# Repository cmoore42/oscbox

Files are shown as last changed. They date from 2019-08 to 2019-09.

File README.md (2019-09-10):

# oscbox
Encoders for the ETC EOS family of lighting consoles using OSC and an Orange Pi Zero

## Overview
The purpose of this project is to create encoder wheels for the ETC EOS family of lighting software.
Specifically, the target is a PC or Mac running the EOS software.
It's possible this would work with a physical lighting console but it hasn't been tested.

The project was inspired by ETC's "lighthack" project.  
Their "box_1" implements two encoder wheels, one for PAN and one for TILT.
I wanted the same, but I wanted four wheels to match the wheels on an Ion console, 
and I wanted the wheels to be multi-function like the console wheels are.

## Details
For detailed descriptions of the code, the hardware, and the enclosure, [see the Wiki](https://github.com/cmoore42/oscbox/wiki)

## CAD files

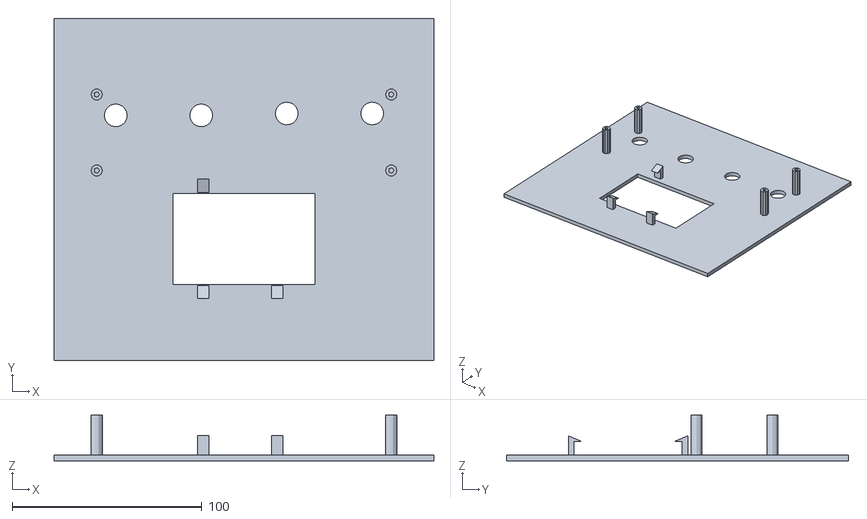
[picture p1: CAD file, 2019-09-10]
enclosure/panel.stl
200.0 x 180.0 x 24.0

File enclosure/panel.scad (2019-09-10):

encoder_zero_x = 100-(45/2)-45-20;
encoder_zero_y = 130-35;
encoder_hole_size = 6;

difference() {
    cube([200, 180, 3]);
    translate([100-(75/2), 40, -5])
        cube([75, 48, 20]);
    translate([100-(45/2)-45, 129, -2])
        cylinder(h=7, r1=encoder_hole_size, r2=encoder_hole_size);
    translate([100-(45/2), 129, -2])
        cylinder(h=7, r1=encoder_hole_size, r2=encoder_hole_size);
    translate([100+(45/2), 130, -2])
        cylinder(h=7, r1=encoder_hole_size, r2=encoder_hole_size);
    translate([100+(45/2)+45, 130, -2])
        cylinder(h=7, r1=encoder_hole_size, r2=encoder_hole_size);   
}

translate([75.5, 32.5, 3]) hook();
translate([114.5, 32.5, 3]) hook();
translate([81.5, 95.5, 3]) rotate([0, 0, 180]) hook();

translate([encoder_zero_x+10, encoder_zero_y+45, 0])
        standoff();
translate([encoder_zero_x+10, encoder_zero_y+5, 0])
        standoff();
translate([encoder_zero_x+165, encoder_zero_y+45, 0])
        standoff();
translate([encoder_zero_x+165, encoder_zero_y+5, 0])
        standoff();

module hook() {
    cube([6, 3, 7.2]);
    translate([6, 7, 7.2])
    rotate([90, 0, 0])
    rotate([0, 270, 0])
    linear_extrude(height=6) {
        polygon([[0,0], [7,0], [7,3], [0, 0]]);
    }      
}

module standoff() {
    difference() {
        cylinder(h=24, r1=3, r2=3);
        translate([0, 0, 15])
            cylinder(h=10, r1=1.5, r2=1.5);
    }
}

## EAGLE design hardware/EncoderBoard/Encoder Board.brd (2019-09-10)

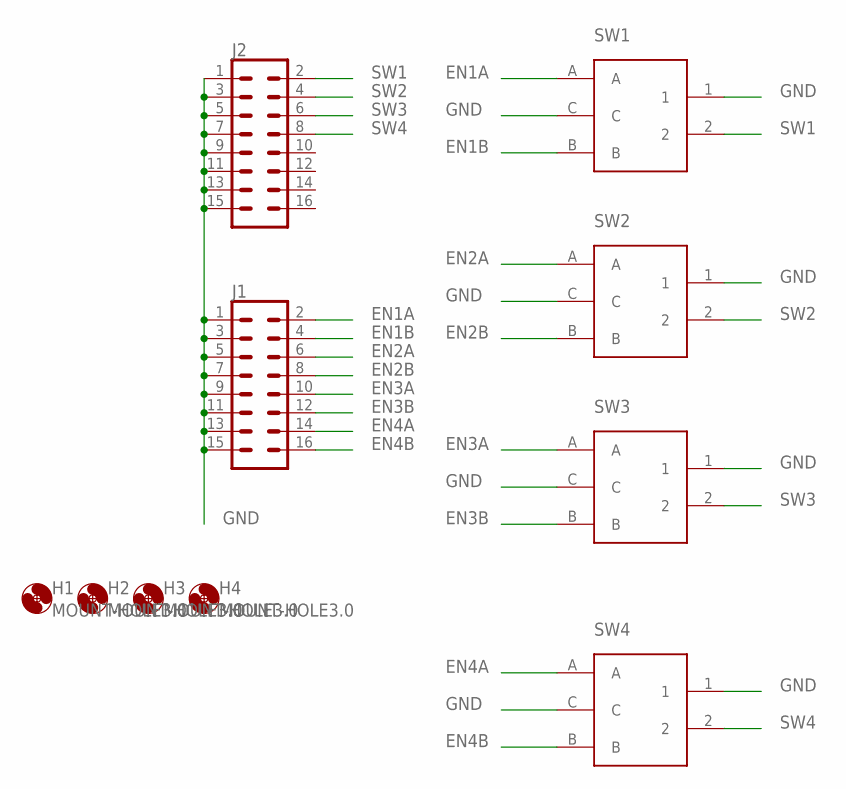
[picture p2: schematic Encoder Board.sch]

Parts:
H1, H2, H3, H4: MOUNT-HOLE3.0; 3,0
J1, J2: CONN_08X2; 2X8
SW1, SW2, SW3, SW4: PEC11R-4220F-S0012-ND; PEC11R-4XXXF-SXXXX

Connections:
EN1A: J1.2, SW1.A
EN1B: J1.4, SW1.B
EN2A: J1.6, SW2.A
EN2B: J1.8, SW2.B
EN3A: J1.10, SW3.A
EN3B: J1.12, SW3.B
EN4A: J1.14, SW4.A
EN4B: J1.16, SW4.B
GND: J1.1, J1.3, J1.5, J1.7, J1.9, J1.11, J1.13, J1.15, J2.1, J2.3, J2.5, J2.7, J2.9, J2.11, J2.13, J2.15, SW1.1, SW1.C, SW2.1, SW2.C, SW3.1, SW3.C, SW4.1, SW4.C
SW1: J2.2, SW1.2
SW2: J2.4, SW2.2
SW3: J2.6, SW3.2
SW4: J2.8, SW4.2

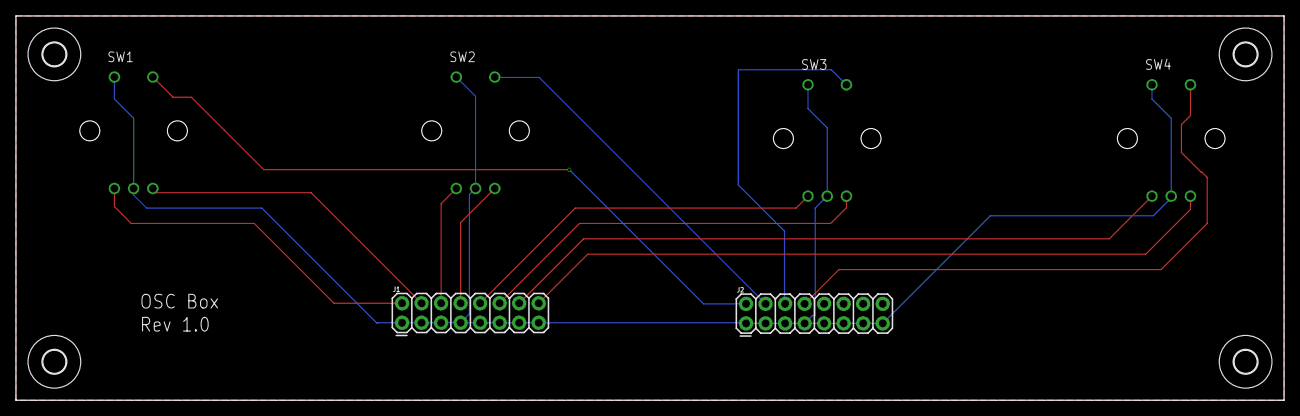
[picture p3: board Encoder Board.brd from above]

Board: 2 copper layers, 165.0 x 50.0 mm, 10 parts (0 on the bottom side), 13 nets.

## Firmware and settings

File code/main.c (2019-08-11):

#include <stdio.h>
#include <pthread.h>
#include <string.h>
#include "tinyosc.h"
#include "i2c.h"
#include "display.h"
#include "encoders.h"
#include "slip.h"
#include "touch.h"
#include "eos.h"
#include "globals.h"

void startup(void);
static void add_button(int x0, int y0, int x1, int y1, touch_callback cb, void *arg, char *text);
void set_category(int category);
void set_encoder_text(int encoder_num, char *text);
void clear_encoder_text(int encoder_num);
void update_wheel(int wheel_num);

int category;

/* Veritcal Layout */
#define ENCODER_WINDOW_SIZE_Y 80
#define CAT_BUTTON_SIZE_Y 60
#define SOFTKEY_SIZE_Y 60
#define SPACE_Y 14

/* Horizontal Layout */
#define SOFTKEY_SIZE_X 140
#define SOFTKEY_SPACE_X 15

int main(int argc, char *argv[]) {
	char c;
	char message[1024];
	int message_len;
	pthread_t recv_thread;
	pthread_t gpio_thread;
	pthread_t touch_thread;
	int i;

	if ((argc > 1) && (argv[1][1] == 'd')) {
		debug = 1;
	}

	if ((argc > 1) && (argv[1][1] == 'v')) {
		verbose = 1;
		debug = 1;
	}

	for (i=0; i<=MAX_WHEELS; i++) {
		wheels[i].category = CAT_NONE;
	}

	category = CAT_COLOR;
	for (i=0; i<NUM_ENCODERS; i++) {
		encoder_map[i] = -1;
	}

	open_port();
	if (slip_fd == -1) {
		return 1;
	}

	if (debug) {
		printf("Serial port open\n");
	}

	encoder_init();

	disp_open();
	disp_clear();

	pthread_create(&recv_thread, NULL, recv_func, NULL);
	pthread_create(&gpio_thread, NULL, encoder_func, NULL);
	pthread_create(&touch_thread, NULL, touch_func, NULL);

	startup();

	pthread_join(recv_thread, NULL);
	pthread_join(gpio_thread, NULL);
	pthread_join(touch_thread, NULL);
}


void category_cb(void *arg) {
	int iarg = (int)arg;
	switch(iarg) {
		case 1:
			set_category(CAT_FOCUS);
			break;
		case 2:
			set_category(CAT_COLOR);
			break;
		case 3:
			set_category(CAT_IMAGE);
			break;
		case 4:
			set_category(CAT_FORM);
			break;
		case 5:
			set_category(CAT_SHUTTER);
			break;
	}

}

void softkey_cb(void *arg) {
	int iarg = (int)arg;
	handle_softkey(iarg);
}

/**
 * Setup code to be run after the threads are started.
 */
void startup() {
	slip_init();

	eos_startup();

	/* Frames around encoder text */
	disp_clear_range(0, 0, 479, ENCODER_WINDOW_SIZE_Y);
	disp_line(0, ENCODER_WINDOW_SIZE_Y, 479, ENCODER_WINDOW_SIZE_Y, COLOR_WHITE);
	disp_line(119, 0, 119, ENCODER_WINDOW_SIZE_Y, COLOR_WHITE);
	disp_line(239, 0, 239, ENCODER_WINDOW_SIZE_Y, COLOR_WHITE);
	disp_line(359, 0, 359, ENCODER_WINDOW_SIZE_Y, COLOR_WHITE);


	/* Category butotns */
	int cat_button_top = ENCODER_WINDOW_SIZE_Y + SPACE_Y;
	int cat_button_bottom = cat_button_top + CAT_BUTTON_SIZE_Y;
	add_button(8, cat_button_top, 
			88, cat_button_bottom,
			category_cb, (void *)1, "Focus");
	add_button(104, cat_button_top, 
			184, cat_button_bottom,
			category_cb, (void *)2, "Color");
	add_button(200, cat_button_top, 
			280, cat_button_bottom,
			category_cb, (void *)3, "Image");
	add_button(296, cat_button_top, 
			376, cat_button_bottom,
			category_cb, (void *)4, "Form");
	add_button(391, cat_button_top, 
			471, cat_button_bottom,
			category_cb, (void *)5, "Shutter");

	/* Softkey buttons */
	int row;
	int col;

	for (row=0; row<2; row++) {
		for (col=0; col<3; col++) {
			int sk_num = row*3 + col + 1;
			int x0 = col*SOFTKEY_SIZE_X + (col+1)*SOFTKEY_SPACE_X;
			int x1 = x0 + SOFTKEY_SIZE_X;
			int y0 = ENCODER_WINDOW_SIZE_Y + CAT_BUTTON_SIZE_Y + row*SOFTKEY_SIZE_Y + (row+2) * SPACE_Y;
			int y1 = y0 + SOFTKEY_SIZE_Y;
			char sk_name[10];
			sprintf(sk_name, "SK %d", sk_num);
			add_button(x0, y0, x1, y1, softkey_cb, (void *)sk_num, sk_name);
		}
	}
}

static void add_button(int x0, int y0, int x1, int y1, touch_callback cb, void *arg, char *text) {
	int center_x = x0 + (x1 - x0) / 2;
	int center_y = y0 + (y1 - y0) / 2;

	disp_clear_range(x0+1, y0+1, x1-1, y1-1);
	disp_line(x0, y0, x1, y0, COLOR_WHITE);
	disp_line(x1, y0, x1, y1, COLOR_WHITE);
	disp_line(x1, y1, x0, y1, COLOR_WHITE);
	disp_line(x0, y1, x0, y0, COLOR_WHITE);
	add_region(x0, y0, x1, y1, cb, arg);

	int text_start_x = center_x - (strlen(text) / 2 * 10);
	int text_start_y = center_y - 8;
	disp_string(text_start_x, text_start_y, text, COLOR_WHITE);

}

void set_category(int c) {
	int wheel_num;
	int encoder_num;

	category = c;

	if (debug) {
		printf("Category %s\n", category_name[category]);
	}

	encoder_num = 0;
	for (wheel_num=0; wheel_num <= MAX_WHEELS; wheel_num++) {
		if (wheels[wheel_num].category == category) {
			encoder_map[encoder_num] = wheel_num;
			set_encoder_text(encoder_num, wheels[wheel_num].name);
			if (debug) {
				printf("Encoder %d maps to wheel %d\n", encoder_num, wheel_num);
			}
			++encoder_num;
			if (encoder_num >= NUM_ENCODERS) {
				break;
			}
		}
	}

	while (encoder_num < NUM_ENCODERS) {
		if (debug) {
			printf("Encoder %d maps to -1\n", encoder_num);
		}
		clear_encoder_text(encoder_num);
		encoder_map[encoder_num++] = -1;
	}
}

void set_encoder_text(int encoder_num, char *text) {
	char trimmed_text[80];
	char value[80];
	char *tok;

	if (debug) {
		printf("Encoder %d is named %s\n", encoder_num, text);
	}
	clear_encoder_text(encoder_num);
	int encoder_start_x = 120*encoder_num + 5;
	int encoder_start_y = 8;

	strcpy(trimmed_text, text);
	if (tok = strchr(trimmed_text, '[')) {
		strcpy(value, tok);
		*tok = '\0';
	}

	tok = strtok(trimmed_text, " ");
	while (tok != NULL) {
		if (debug) {
			printf("Line: '%s'\n", tok);
		}
		disp_string(encoder_start_x, encoder_start_y, tok, COLOR_WHITE);
		tok = strtok(NULL, " ");
		encoder_start_y += 16;
	}
	disp_string(encoder_start_x, encoder_start_y, value, COLOR_WHITE);
}

void clear_encoder_text(int encoder_num) {
	if (debug) {
		printf("Clear encoder name %d\n", encoder_num);
	}
	switch(encoder_num) {
		case 0:
			disp_clear_range(0, 0, 118, ENCODER_WINDOW_SIZE_Y-1);
			break;
		case 1:
			disp_clear_range(120, 0, 238, ENCODER_WINDOW_SIZE_Y-1);
			break;
		case 2:
			disp_clear_range(240, 0, 358, ENCODER_WINDOW_SIZE_Y-1);
			break;
		case 3:
			disp_clear_range(360, 0, 479, ENCODER_WINDOW_SIZE_Y-1);
			break;
	}
}

void update_wheel(int wheel_num) {
	set_category(category);
}

/**
 * Set the text for a softkey button
 *
 * @param sk_num Softkey numbers, 1..6
 */

void set_sk_text(int sk_num, char *text) {
	int row;
	int col;
	int x0, y0;
	int x1, y1;

	if (sk_num > 6) {
		return;
	}

	row = (sk_num - 1) / 3;
	col = (sk_num - 1) % 3;

	x0 = col*SOFTKEY_SIZE_X + (col+1)*SOFTKEY_SPACE_X;
	x1 = x0 + SOFTKEY_SIZE_X;
	y0 = ENCODER_WINDOW_SIZE_Y + CAT_BUTTON_SIZE_Y + row*SOFTKEY_SIZE_Y + (row+2) * SPACE_Y;
	y1 = y0 + SOFTKEY_SIZE_Y;

	disp_clear_range(x0+1, y0+1, x1-1, y1-1);

	int center_x = x0 + (x1 - x0) / 2;
	int center_y = y0 + (y1 - y0) / 2;

	int text_start_x = center_x - (strlen(text) / 2 * 10);
	int text_start_y = center_y - 8;
	disp_string(text_start_x, text_start_y, text, COLOR_WHITE);
}

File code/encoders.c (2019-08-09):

#include <stdio.h>
#include <gpiod.h>
#include <signal.h>
#include "encoders.h"
#include "eos.h"
#include "i2c.h"
#include "globals.h"

/**
 * This file covers input from the encoders and buttons.
 * This includes monitoring the GPIO pins and interacting
 * with the I2C I/O extender.
 */

int i2c_fd;
void usr1_handler(int sig);


/**
 * encoder thread
 * This function is executed in a separate thread.
 * It monitors the GPIO lines (encoders and buttons)
 * and responds to changes.
 *
 * GPIO6 is connected to the INT line of the I/O
 * expander, and the expander is programmed to interrupt
 * on any line change.
 *
 * This function monitors GPIO6 for a falling edge, indicating
 * an interrupt.  When GPIO6 goes low it sends I2C commands
 * to read the current state of the encoders and buttons
 * and acts accordingly.
 */

void* encoder_func(void *ptr) {
	char line[80];
	struct gpiod_chip *chip;
	struct gpiod_line *gpio_line;
	struct gpiod_line_event event;
	struct timespec ts = {0, 1000000};
	int rv;
	uint8_t current_encoders;
	uint8_t previous_encoders;

	signal(SIGUSR1, usr1_handler);

	chip = gpiod_chip_open("/dev/gpiochip0");
        if (!chip) {
                perror("gpiod_chip_open");
                return NULL;
        }

        gpio_line = gpiod_chip_get_line(chip, 6);
        if (!gpio_line) {
                perror("gpiod_chip_get_line");
                gpiod_chip_close(chip);
                return NULL;
        }

        rv = gpiod_line_request_falling_edge_events(gpio_line, "GPIO6");
        if (rv) {
                perror("gpiod_line_request_falling_edge_events");
                gpiod_chip_close(chip);
                return NULL;
        }

	previous_encoders = i2c_read(i2c_fd, REG_GPIOA);

	/* If there is user input (button, encoder, etc), handle it */
	while (1) {

		do {
			/* Clear interrupts */
			i2c_read(i2c_fd, REG_INTCAPA);
			i2c_read(i2c_fd, REG_INTCAPB);
			rv = gpiod_line_event_wait(gpio_line, &ts);
		} while (rv <= 0);

		rv = gpiod_line_event_read(gpio_line, &event);
		if (!rv) {
			/* Got an interrupt */
			char cmd[80];

			if (verbose) {
				printf("event: %d timestamp: [%8ld.%09ld]\n",
						event.event_type, event.ts.tv_sec, event.ts.tv_nsec);
			}

			current_encoders = i2c_read(i2c_fd, REG_GPIOA);
			if (current_encoders != previous_encoders) {
				handle_encoders(previous_encoders, current_encoders);
				previous_encoders = current_encoders;
			}
		}
	}
}

void encoder_init() {
	int i;

	i2c_fd = i2c_open(I2C_BUS, I2C_ADDR);
	if (i2c_fd < 0) {
		perror("i2c_open");
		return;
	}
	i2c_init(i2c_fd);
	if (debug) {
		printf("I2C initialized\n");
		printf("I2C registers:\n");
		for (i = 0; i < 0x16; i++) {
			printf("0x%02x: 0x%02x\n", i, i2c_read(i2c_fd, i));
		}
	}
}

void usr1_handler(int sig) {

	printf("I2C registers:\n");
	printf("REG_INTCAPA: 0x%02x\n", i2c_read(i2c_fd, REG_INTCAPA));
	printf("REG_INTCAPB: 0x%02x\n", i2c_read(i2c_fd, REG_INTCAPB));
	printf("REG_GPIOA: 0x%02x\n", i2c_read(i2c_fd, REG_GPIOA));
}

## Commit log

2019-07-27 Added I2C functions. Files i2c.c and i2c.h for communicating with the I2C based I/O expander. GPIO function modified to watch GPIO6 for an interrupt, then read the encoder values using I2C.
2019-07-29 Implemented interrupt processing from the I2C expander. The I2C expander now sends an interrupt when a GPIO pin changes. The main code sees the interrupt on GPIO line 6, reads the state of GPIO port 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
    [main.c]
2019-07-30 Added tracking of wheel catagories Added a debug option Increased the number of wheels Fixed a bug in name_to_param
    [main.c]
2019-08-05 Added code for writing to the frame buffer Also added a variety of test programs used during development
2019-08-06 Added code for processing touchscreen input. Cleaned up includes in main.c Added functions in main.c for creating buttons.
2019-08-06 Added category select buttons. Soft buttons on the touchscreen for focus, color, image, form, and shutter. Encoder names are displayed based on current category.
2019-08-06 Names for encoders are split over multiple lines
2019-08-06 Update encoder labels when values change
2019-08-08 Added encoder->wheel mapping in eos.c
2019-08-09 Added softkey buttons Parameterized the layout on the screen Added a SIGUSR1 handler, to dump the I2C registers Move the interrupt clear to just before the event wait
2019-08-11 Made the buttons and display boxes white on blue.
2019-09-10 Restructuring the repo
    Moved all code into a "code" directory, created directories for hardware
    and enclosure designs.
2019-09-10 Added PC board design.
    [DRILEGEND.CFG, Encoder Board.brd, Encoder Board.sch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]
2019-09-10 Added SCAD and STL files for the 3D printed panel.
    [panel.scad, panel.stl]

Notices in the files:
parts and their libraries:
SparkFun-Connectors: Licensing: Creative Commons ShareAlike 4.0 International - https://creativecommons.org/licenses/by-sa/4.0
